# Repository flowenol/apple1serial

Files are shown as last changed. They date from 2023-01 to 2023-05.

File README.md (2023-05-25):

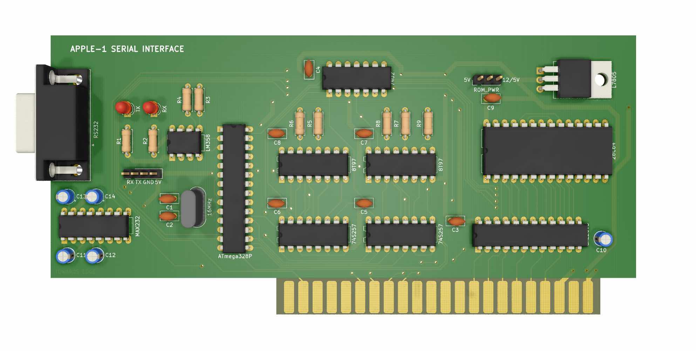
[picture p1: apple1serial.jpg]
apple1serial


# apple1serial

This repository contains firmware and gerber files for the Apple-1 Serial Interface expansion card.

## Description

This project aims to provide an alternative to the Apple Cassette Interface for the Apple-1 computer with use of the serial
communication (9600/8-N-1). The expansion card is based around inexpensive and easily available ATMega328P MCU which operates
as half-duplex UART. The best way to connect the device to a regular modern PC is to use FTDI FT232RL USB dongle via exposed pin headers (5V TTL) or traditionally via standard DB9 RS232 connector.

The board tries to mimic the original ACI behaviour via the modified ACI loader program `$C100` located on the on-board ROM.
The usual way to communicate with the device is to hook it up to a PC and use a terminal emulator program to send and
receive binary files representing the Apple-1 memory contents. An alternative is to use custom software/scripts like the
`scripts/transfer.py` python script.

In order to learn how to use the loader program, please refer to the original ACI documentation or the instructions provided [here](https://www.sbprojects.net/projects/apple1/aci.php).

Some Apple-1 program binaries ready to be downloaded are available [here](https://drive.google.com/file/d/1G0ycKSszlr45RE8Rp6eW-0qxz4MS9qDN/view?usp=sharing).

## Memory map

| address | function |
| --- | --- |
| `$C0FC-$C0FF` | these addresses contain the 'A1SI' string which might be used to determine whether the A1SI expansion card is present. |
| `$C100-$C7FF` | address space reserved for on-board ROM. |
| `$C100` | the original ACI loader program adapted to the A1SI. |
| `$C300` | "teletype on apple-1" test program - the data from remote terminal appears on Apple-1 screen. |
| `$C400` | "teletype on remote" test program - the data from Apple-1 appears on remote terminal. |
| `$C500` | 0-255 repeating counter - all possible bytes are repeatedly sent to remote terminal. |
| `$C600` | serialmonitor - the well known Woz Monitor variation, but now on the remote terminal. |

entries for programmers:

| address | function |
| --- | --- |
| `$C000` | ready flag - contains 0x01 if the device is ready to write/read, 0x00 otherwise. |
| `$C080` | read address - the location for data read from the interface, first read of this address switches the device to read mode. |
| `$C081` | write address - the location for data to be written via the interface. First write operation to this address switches the device to write mode. If you want to immediately write bytes after switching to write mode you must wait for the ready flag at `$C000` to be set. |
| `$C23A` | software reset routine - resets the MCU. |
| `$C1EC` | block read routine - reads data from the interface and writes to the specified address range. |
| `$C213` | block write routine - reads the data from the specified address range and write via the interface. |
| `$0034` | lower byte of the end address for block read/write routines. |
| `$0035` | upper byte of the end address for block read/write routines. |
| `$0036` | lower byte of the beginning address for block read/write routines. |
| `$0037` | upper byte of the beginning address for block read/write routines. |

## Contents

The contents of this repository are as following:

* gerber/ - gerber files needed to manufacture the PCB
* firmware/ - contains source code for the ATMega328 MCU firmware
* mapping/ - contains EQN and JED files for GAL20V8 based address decoder for the board
* src/ - contains the 6502 assembly sources for the A1SI onboard ROM routines
* scripts/ - contains python based file transfer utility

## Mappings

There are two .jed files for the GAL20V8 based address decoder:

1. **address_decoder-C000.jed** - defines the standard mapping where the device mimics the original ACI loader program at `$C100`.
2. **address_decoder-C300.jed** - defines an alternative mapping to run Apple-1 Serial Interface together with the original ACI within the same system.
All program and hardware entries are shifted by offset `$300`, so the loader program can be accessed at `$C400`.
2. **address_decoder-C600.jed** - defines an alternative mapping to run Apple-1 Serial Interface together with both the original and Improved ACI 2.0 (by Uncle Bernie) within the same system.
All program and hardware entries are shifted by offset `$600`, so the loader program can be accessed at `$C700`.

Please be sure to program the ROM with the bin image corresponding to the selected mapping.

You can use the convenient `make` targets to burn ROM and GAL, if you have the `minipro` utility installed:
```bash
make burn-C000-gal
make burn-C000-rom

make burn-C300-gal
make burn-C300-rom

make burn-C600-gal
make burn-C600-rom
```

## Requirements

You need the following to successfully build the firmware:

* [xa](https://www.floodgap.com/retrotech/xa/) cross assembler.
* [avr-gcc](https://gcc.gnu.org/wiki/avr-gcc) toolchain.
* [avr-libc](https://www.nongnu.org/avr-libc/) set of libraries.
* [AVRDUDE](https://www.nongnu.org/avrdude/) AVR programmer software or equivalent to program the ATMega328P MCU.
* Software capable of translating the .eqn files into .jed's. I used for this purpose the DOS based EQN2JED from OPALjr PLD Development Package. This is only required if you wish to make some changes to the GAL based address decoder. The default .jed file should be fine for most users.
* EEPROM programmer to write ROM and GAL. I used [TL866](http://autoelectric.cn/EN/TL866_main.html) programmer for this purpose. It can also program the ATMega328P MCU.
* You can use the [minipro](https://gitlab.com/DavidGriffith/minipro/) utility to write ROM, GAL and MCU.

## How to build?

To build the firmware just type:

`make`

And to clean the build:

`make clean`

## Applesoft BASIC support

You can also `LOAD` and `SAVE` your Applesoft BASIC programs thanks to the branch of the
applesoft-lite project which has been modified to be compatible with the A1SI expansion card:

http://github.com/flowenol/applesoft-lite

## ACItest

You can use the A1SI expansion card to [test the reliability](http://github.com/flowenol/ACItest) of the Apple-1 Cassette Interface.

## How to install hardware?

Solder the "C" memory segment line near 74154 demultiplexer to the "T" signal line.
Afterwards just put the board in right orientation (as marked on the PCB) in the Apple-1 expansion slot.
Or you can use the port expander if the on-board slot is already occupied:

https://github.com/flowenol/Apple1ExpanderPcb

## PCB

Gerber files can be found in the `gerber/` directory.
The previous version of the board without DB9 connector can be found in the `gerber/noDB9` directory.
The KiCad project files with board design and schematics can be found here:

http://github.com/flowenol/Apple1SerialPcb

## Bill of materials

| name | part | quantity |
| --- | --- | --- |
| C1, C2  | Ceramic 22pF  | 2 |
| C3..C9  | Ceramic 100nF | 7 |
| C10 | Electrolytic 22uF | 1 |
| C11..C14| Electrolytic 10uF | 4 |
| R1, R2  | 0.68K 0.25W | 2 |
| R3..R9  | 1K 0.25W | 7 |
| XTAL1 | 16Mhz crystal HC49 low profile | 1 |
| ATmega328P1 | ATMega328P microcontroller DIP28 | 1 |
| 7402 | 7402 quad 2 input NOR gates DIP14 | 1 |
| 74S257mux1,2 | 74S257 quad multiplexers DIP16 | 2 |
| 8T97buf1,2 | 8T97N hex tristate buffers DIP16 | 2 |
| 20V8B1  | GAL20V8 SPLD (35ns or less) DIP24 | 1 |
| AT28C64B1 | AT28C64 ROM or similar DIP-28 | 1 |
| MAX232 | Maxim MAX232 RS-232 driver/receiver DIP16 | 1 |
| LED1 | LM358N double op amp DIP8 | 1 |
| TX_LED1, RX_LED1 | LED phi 3mm | 2 |
| L7805 | LM7805 regulator (optional) | 1 |
| SERIAL1 | 1x4 2.54mm pin header | 1 |
| RS232 | DB9 horizontal female header (mounting holes offset 7.48mm) | 1 |  
| ROM_PWR1| 1x3 2.54mm pin header (optional -  make solder blob to "5V" instead) | 1 |

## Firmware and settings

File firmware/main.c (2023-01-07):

#ifndef F_CPU
#define F_CPU 16000000UL
#endif

// this seems to be the upper limit, above that some data is not received
#define BAUD 9600

#include <avr/io.h>
#include <avr/interrupt.h>
#include <util/setbaud.h>

#define DATA_READ_LINE PB0
#define DATA_WRITE_LINE PD7
#define STATUS PD6

#define DATA0 PB1
#define DATA1 PB2
#define DATA2 PB3
#define DATA3 PB4
#define DATA4 PB5
#define DATA5 PD2
#define DATA6 PD3
#define DATA7 PD4

#define BUFFER_SIZE 100

typedef enum {NONE, READ, WRITE} mode_t;
volatile mode_t mode = NONE;

volatile uint8_t data = 0x00;
volatile uint8_t upper_part = 0x00;
volatile uint8_t lower_part = 0x00;

volatile uint8_t data_write_interrupt_count = 0;
volatile uint8_t data_read_interrupt_count = 0;

// receive buffer
volatile uint8_t receive_buffer[BUFFER_SIZE];
volatile int8_t receive_index = -1;

void ready() {
    PORTD |= _BV(STATUS);
}

void not_ready() {
    PORTD &= ~(_BV(STATUS));
}

void put_data() {
    upper_part = (PORTD & 0xe3) | ((0xe0 & receive_buffer[0])>>3);
    lower_part = (PORTB & 0xc1) | ((0x1f & receive_buffer[0])<<1);

    PORTD = upper_part;
    PORTB = lower_part;
}

// Registers: PCMSK0, PCMSK1, PCMSK2 :registers that enable or disable
// pin-change interrupts on individual pins.
// PCICR : a register where the three least significant bits enable or disable
// pin change interrupts on a range of pins, i.e.
// {0,0,0,0,0,PCIE2,PCIE1,PCIE0}, where PCIE2 maps to PCMSK2, PCIE1 maps to
// PCMSK1 and PCIE0 maps to PCMSK0.
void setup() {

    // set input on DATA_READ_LINE
    DDRB &= ~(_BV(DATA_READ_LINE));
    // interrupt on DATA_READ_LINE change
    PCMSK0 |= _BV(PCINT0);
    PCICR |= _BV(PCIE0);

    // set input on DATA_WRITE_LINE
    DDRD &= ~(_BV(DATA_WRITE_LINE));
    // interrupt on DATA_WRITE_LINE change
    PCMSK2 |= _BV(PCINT23);
    PCICR |= _BV(PCIE2);

    UBRR0H = UBRRH_VALUE;
    UBRR0L = UBRRL_VALUE;

    UCSR0A = 0x00;
    UCSR0C = 0x00;
    // 8 bits of data, 1 stop bit, no parity
    UCSR0C = _BV(UCSZ00) | _BV(UCSZ01);
    // TXD pullup
    PORTD |= _BV(PD1);

    // interrupt on DATA_READ_LINE change
    PCMSK0 |= _BV(PCINT0);
    PCICR |= _BV(PCIE0);

    // set output on status
    DDRD |= _BV(STATUS);
    not_ready();

    // enable global interrupts
    sei();
}

// data read line
ISR(PCINT0_vect) {
    if (data_read_interrupt_count == 0) {
        if (mode != READ) {
            mode = READ;

            // enable RXD and it's interrupt
            UCSR0B = _BV(RXEN0) | _BV(RXCIE0);

            // set output on data pins
            DDRD |= _BV(DATA5) | _BV(DATA6) | _BV(DATA7);
            DDRB |= _BV(DATA0) | _BV(DATA1) | _BV(DATA2) | _BV(DATA3) | _BV(DATA4);

            receive_index = -1;
            not_ready();
            data_read_interrupt_count = 1;
            return;
        }

        if (receive_index > -1) {
            uint8_t i;
            for (i = 1; i <= receive_index; i++) {
                receive_buffer[i - 1] = receive_buffer[i];
            }
            receive_index--;

            if (receive_index == -1) {
                not_ready();
            } else {
                // put next byte from receive buffer
                put_data();
            }
        }
        data_read_interrupt_count = 1;
    } else {
        data_read_interrupt_count = 0;
    }
}

// data write line
ISR(PCINT2_vect) {
    upper_part = PINB;
    lower_part = PIND;

    if (data_write_interrupt_count == 0) {
        if (mode == WRITE) {
            upper_part = upper_part >> 1;
            upper_part &= 0x1f;

            lower_part = lower_part << 3;
            lower_part &= 0xe0;

            // set status to not ready
            PORTD &= ~(_BV(STATUS));

            // send byte
            loop_until_bit_is_set(UCSR0A, UDRE0);
            UDR0 = upper_part | lower_part;
        } else {
            if (mode == READ) {
                // zero all outputs
                PORTD &= 0xe3;
                PORTB &= 0xc1;
            }
            mode = WRITE;

            // enable TXD interrupt and it's interrupt
            UCSR0B =  _BV(TXEN0) | _BV(TXCIE0);

            // set input on data pins
            DDRD &= ~(_BV(DATA5) | _BV(DATA6) | _BV(DATA7));
            DDRB &= ~(_BV(DATA0) | _BV(DATA1) | _BV(DATA2) | _BV(DATA3) | _BV(DATA4));

            ready();
        }
        data_write_interrupt_count = 1;
    } else {
        data_write_interrupt_count = 0;
    }
}

ISR(USART_RX_vect)
{
    if (mode == READ) {
        data = UDR0;

        if (receive_index >= BUFFER_SIZE - 1) {
            receive_index = -1;
        }

        receive_buffer[++receive_index] = data;

        // always put first byte from receive buffer
        put_data();

        ready();
    }
}

ISR(USART_TX_vect)
{
    if (mode == WRITE) {
        ready();
    }
}

int main(void) {
    setup();

    for(;;){
        // only interrupt driven
    }
    return 0;   /* never reached */
}

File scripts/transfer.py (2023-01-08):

import sys
import serial
import select
import signal
import time

bytes_processed: int  = 0

def print_usage_and_exit():
    print('Usage: python serialfile.py -in <serial device> [ > file ]', file=sys.stderr)
    print('Usage: python serialfile.py -out <serial device> < file', file=sys.stderr)
    exit(1)


def get_serial(port: str) -> serial.Serial:
    s = serial.Serial()
    s.baudrate = 9600
    s.parity = serial.PARITY_NONE
    s.stopbits = serial.STOPBITS_ONE
    s.bytesize = serial.EIGHTBITS
    s.port = port
    s.timeout = None
    s.write_timeout = None
    return s

def data_ready_on_stdin():
    return bool(select.select([sys.stdin], [], [], 0)[0])

def data_ready_on_port(port: serial.Serial):
    return bool(select.select([port.fileno()], [], [], 0)[0])


def handle_inbound_transmission(port: str):
    global bytes_processed

    with get_serial(port) as s:
        print('Waiting for data... ', file=sys.stderr, end='', flush=True)
        while not data_ready_on_port(s):
            pass
        print('OK', file=sys.stderr)

        s.timeout = 1
        while True:
            data = s.read()
            if len(data) > 0:
                sys.stdout.buffer.write(data)
                bytes_processed += len(data)
            else:
                break
        print('Transmission finished', file=sys.stderr)


def handle_outbound_transmission(port: str):
    global bytes_processed

    if not data_ready_on_stdin():
        print_usage_and_exit()

    with get_serial(port) as s:
        data = sys.stdin.buffer.read()
        while len(data) > 0:
            s.write(data)
            bytes_processed += len(data)
            data = sys.stdin.buffer.read()


"""
This utility receives/sends files via selected serial port to the
Apple-1 Serial Interface card.

This utility requires pyserial module to be installed:

pip3 install pyserial
"""
if __name__ == "__main__":

    if len(sys.argv) != 3:
        print_usage_and_exit()

    def print_bytes_processed_and_exit(status: int):
        print(f'Total bytes processed: {bytes_processed}', file=sys.stderr)
        exit(status)

    # terminate silently on SIGINT
    signal.signal(signal.SIGINT, lambda s, fr: print_bytes_processed_and_exit(1))

    if sys.argv[1] == '-in':
        handle_inbound_transmission(sys.argv[2])

    elif sys.argv[1] == '-out':
        handle_outbound_transmission(sys.argv[2])

    else:
        print(f'Unknown option: {sys.argv[1]}', file=sys.stderr)
        print_usage_and_exit()

    print_bytes_processed_and_exit(0)

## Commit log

2020-07-03 address decoder pin change & last command bug fix
    [main.c]
2021-01-07 hardware recognition memory addresses added, fixed apple-1 to remote test program
    [main.c]
2021-02-06 changed assembly source files extension to *.a65
2021-03-01 Add PCB link to README.md
2021-03-10 Added gerber files
    [Apple1Serial-B_Cu.gbl, Apple1Serial-B_Mask.gbs, Apple1Serial-B_SilkS.gbo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]
2021-03-24 Added bill of materials to README.md
2023-01-07 removing inlined methods causing problems with some versions of avr-ld
    [main.c]
2023-01-09 BOM fix
2023-01-13 fixed resistor rating in BOM
2023-05-25 board with DB9 RS232 connector
    [Apple1Serial-B_Cu.gbl, Apple1Serial-B_Mask.gbs, Apple1Serial-B_SilkS.gbo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]
